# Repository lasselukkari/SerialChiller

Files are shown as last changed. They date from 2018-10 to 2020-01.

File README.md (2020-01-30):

# SerialChiller
> ESP32 and MAX3232 based wireless RS232 adapter for the Internet of old things.





## Build video
DuinoDCX Demo Video (https://www.youtube.com/watch?v=_-YNTO3l9uc)

## Wiring
The wiring is implemented as DTE. RS232 TX and RX are connected to the default Serial2 pins IO16 and IO17. RTS is connected to IO21 and CTS to IO22.

## Partlist
| Part | Value | Package | Part # |
| --- | --- | --- | --- |
| C1 | 0.1uF | C0603 | C0603X104K5RAC |
| C2 | 0.1uF | C0603 | C0603X104K5RAC |
| C3 | 0.1uF | C0603 | C0603X104K5RAC |
| C4 | 0.1uF | C0603 | C0603X104K5RAC |
| C5 | 0.1uF | C0603 | C0603X104K5RAC |
| C6 | 22uf | A/3216-18R | T491A226M010AT |
| C7 | 22uf | A/3216-18R | T491A226M010AT |
| C8 | 22uF | C1206 | LMK316ABJ226KL-T |
| C9 | 0.1uF | C0603 | C0603X104K5RAC |
| C10 | 0.1uF | C0603 | C0603X104K5RAC |
| ESP-WROOM-32 | ESP-WROOM-32 | ESP-WROOM-32 | ESP-WROOM-32 |
| IC1 | LM1117IMPX-3.3 | SOT223 | NCV1117ST33T3G |
| MAX3232 | MAX3232CSE | SO16 | MAX3232IDR |
| R1 | 10k | R0603 | NRC06J103TRF |
| RS232 | 56F402-001 | 56F402-001 | 56F402-001 |
| S1 | B3U-1000P | SW_B3U-1000P | B3U-1000P |
| S2 | B3U-1000P | SW_B3U-1000P | B3U-1000P |
| SERIAL | Serial | 1X02 | pinhead |
| VIN | Power | 1X02 | pinhead |

## PCB Thickness
Use 0.8mm thick pcb to make the board align horisontally with the case.

## Other components
### Case


The plastic housing is taken from a cheap vga break out board available from multiple different vendors. Search eBay or Aliexpress for `DB15 breakout`. 

### USB to TTL Cable

USB to TTL serial adapter cable for powering and flashing the board.

### Strain Relief

Print the strain_relief.stl out of any plastic material to properly secure the cable to the housing.

### Cord Sleeve


The black 4mm cord sleeve is available from multiple different vendors. Snip the end off to make it fit. Search eBay or Aliexpress for `4mm cord sleeve` or `4mm strain relief`.

## Installation
Make sure that the thumb screws are properly tightened or remove them completely. A loose thumb screw may short circuit the electronics.

When used with an extension cable the thumb screws can be replaced with #4-40 jackscrews.



## Power Supply
Any standard usb charger will work fine. The average power consumption is under 500mA.

## Example projects
https://github.com/lasselukkari/DuinoDCX

https://github.com/AlphaLima/ESP32-Serial-Bridge

## License
Creative Commons — Attribution 4.0 International

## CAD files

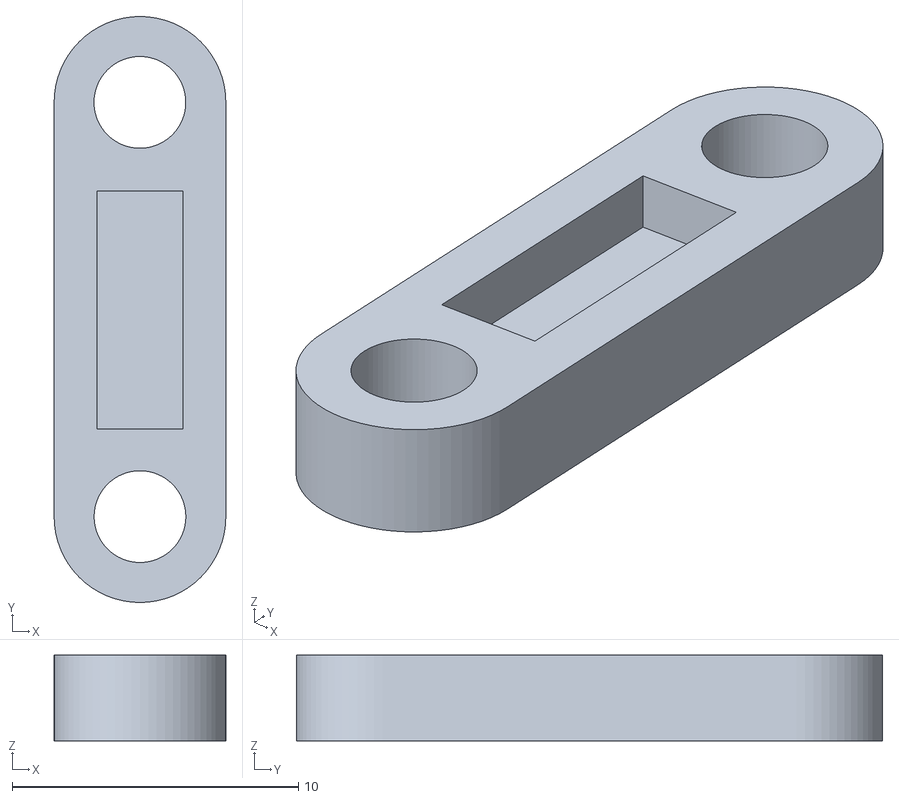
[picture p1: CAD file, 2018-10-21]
stl/strain_relief.stl
6.00 x 20.5 x 3.00

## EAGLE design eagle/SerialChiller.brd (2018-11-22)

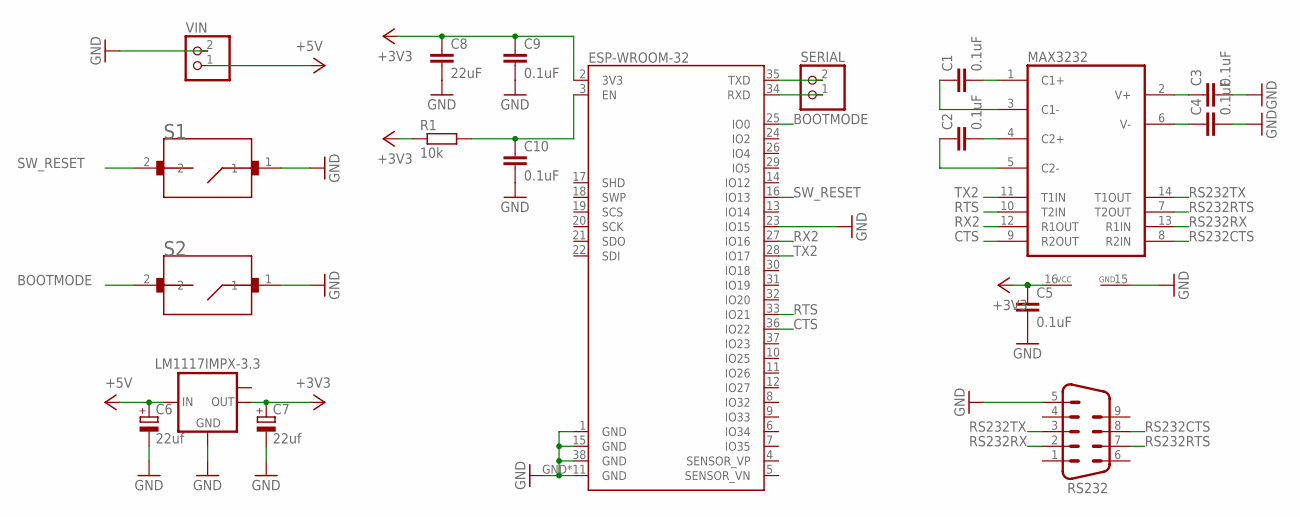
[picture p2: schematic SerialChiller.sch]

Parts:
C1, C2, C3, C4, C5, C9, C10: 0.1uF; C0603
C6, C7: 22uf; A/3216-18R
C8: 22uF; C1206
ESP-WROOM-32: ESP-WROOM-03
IC1: LM1117IMPX-3.3; SOT223
MAX3232: MAX3232CSE; SO16
R1: 10k; R0603
RS232: M09HP
S1, S2: B3U-1000P; SW_B3U-1000P
SERIAL: Serial; 1X02
VIN: Power; 1X02

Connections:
+3V3: C5.1, C7.+, C8.1, C9.1, ESP-WROOM-32.2 (3V3), IC1.2 (OUT), MAX3232.16 (VCC), R1.1
+5V: C6.+, IC1.3 (IN), VIN.1
BOOTMODE: ESP-WROOM-32.25 (IO0), S2.2
C1+: C1.2, MAX3232.1 (C1+)
C1-: C1.1, MAX3232.3 (C1-)
C2+: C2.2, MAX3232.4 (C2+)
C2-: C2.1, MAX3232.5 (C2-)
CTS: ESP-WROOM-32.36 (IO22), MAX3232.9 (R2OUT)
ENABLE: C10.1, ESP-WROOM-32.3 (EN), R1.2
GND: C3.2, C4.2, C5.2, C6.-, C7.-, C8.2, C9.2, C10.2, ESP-WROOM-32.1 (GND), ESP-WROOM-32.15 (GND), ESP-WROOM-32.23 (IO15), ESP-WROOM-32.38 (GND), ESP-WROOM-32.GND, ESP-WROOM-32.GND1 (GND), ESP-WROOM-32.P$1 (GND), ESP-WROOM-32.P$2 (GND), ESP-WROOM-32.P$3 (GND), ESP-WROOM-32.P$4 (GND), ESP-WROOM-32.P$5 (GND), ESP-WROOM-32.P$6 (GND), ESP-WROOM-32.P$7 (GND), ESP-WROOM-32.P$8 (GND), ESP-WROOM-32.P$9 (GND), IC1.1 (GND), MAX3232.15 (GND), RS232.5, S1.1, S2.1, VIN.2
RS232CTS: MAX3232.8 (R2IN), RS232.8
RS232RTS: MAX3232.7 (T2OUT), RS232.7
RS232RX: MAX3232.13 (R1IN), RS232.2
RS232TX: MAX3232.14 (T1OUT), RS232.3
RTS: ESP-WROOM-32.33 (IO21), MAX3232.10 (T2IN)
RX1: ESP-WROOM-32.34 (RXD), SERIAL.1
RX2: ESP-WROOM-32.27 (IO16), MAX3232.12 (R1OUT)
SW_RESET: ESP-WROOM-32.16 (IO13), S1.2
TX1: ESP-WROOM-32.35 (TXD), SERIAL.2
TX2: ESP-WROOM-32.28 (IO17), MAX3232.11 (T1IN)
VS+: C3.1, MAX3232.2 (V+)
VS-: C4.1, MAX3232.6 (V-)

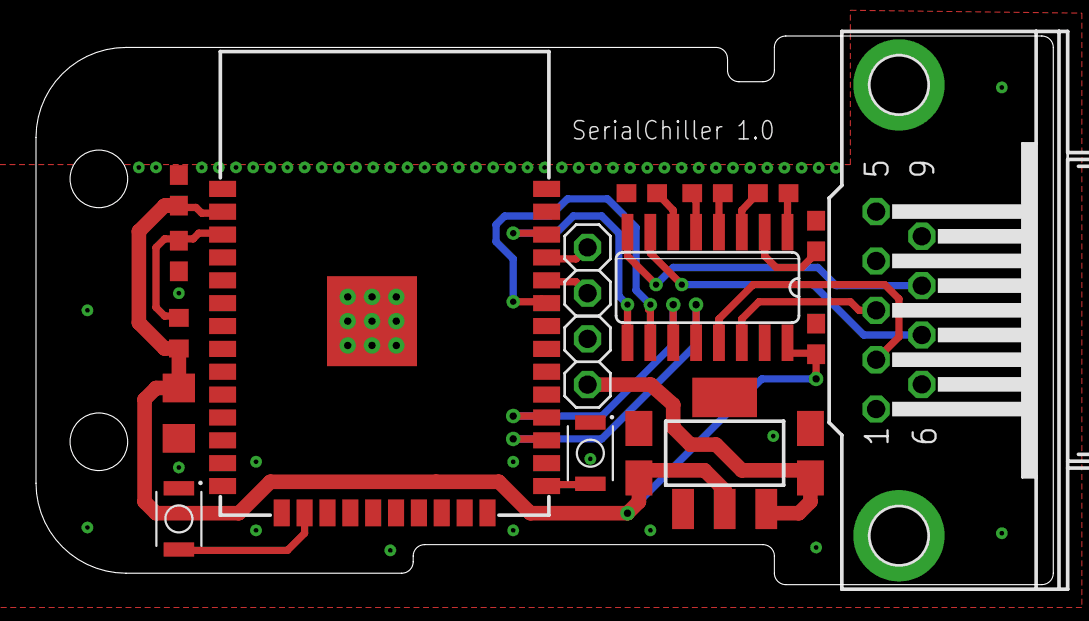
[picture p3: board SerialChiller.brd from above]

Board: 2 copper layers, 56.5 x 30.5 mm, 19 parts (0 on the bottom side), 22 nets.

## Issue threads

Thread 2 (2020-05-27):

Interrest in SerialChiller

Wouteroosterwijk, 2020-05-27:
Dear Lasse,

My name is Wouter Oosterwijk and i live in the Netherlands.
Your SerialChiller design really got my interrest as i am rebuilding 2 flightcases with Behringer DCX2496 inside; attached some pictures. There is no space left for adding a RS232 port in the panel and offcourse i would like to update designs to a better workable solutions without using cables. That's why i got interrested in your RS232-Wifi design, which even can run by itself (course the software is being installed to it and you can easily communite with the device by just using the IP-adres).
I would love to try this.....how can we arrange 2 of these?

Looking forward to your reply.
Kind regards,
Wouter Oosterwijk
Burg. den Hoedstraat 12
2957KA Nieuw-Lekkerland
The Netherlands
wouteroosterwijk@hotmail.com

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

lasselukkari, 2020-06-03:
Hi. I'm super busy with work at the moment. I will get back to you soon.

Wouteroosterwijk, 2020-06-06:
Hi,

Sure...no problem, if you have a moment left, than you can always contact me.

Gr

Wouter

Outlook voor Android downloaden<https://aka.ms/ghei36>

________________________________
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

Closed 2020-06-13.

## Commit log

2018-10-21 Add content
    [SerialChiller.brd, SerialChiller.sch, strain_relief.stl]
2018-11-22 Remove gerbers
